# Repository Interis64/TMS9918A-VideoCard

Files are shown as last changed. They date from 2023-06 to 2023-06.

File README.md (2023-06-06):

# TMS9918A-VideoCard

Interis 64 Video Card with TMS9918A chip

## Notes

The TMS9918A only requires 4116 DRAM, but to simplify voltage requirements, 4164 DRAM is used instead, as 4164 DRAM only requires a single 5V supply, while 4116 requires a 12V and -5V supply as well. The extra memory space is unused.

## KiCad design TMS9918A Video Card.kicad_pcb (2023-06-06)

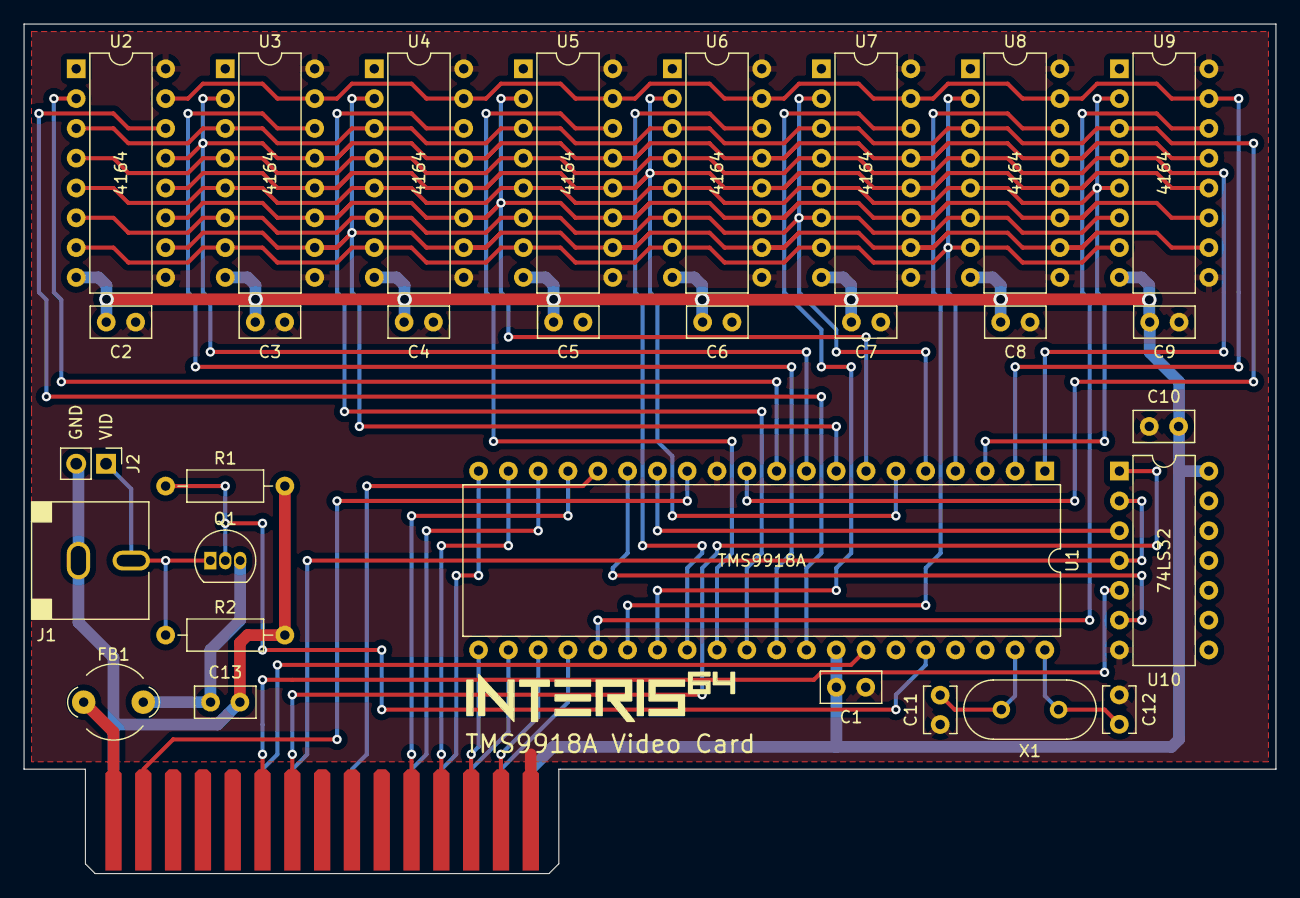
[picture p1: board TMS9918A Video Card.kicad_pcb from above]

Board: 2 copper layers, 106.7 x 72.4 mm, 31 parts (0 on the bottom side), 44 nets.

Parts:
C1, C2, C3, C4, C5, C6, C7, C8, C9, C10, C13: 0.1µF; C_Disc_D5.0mm_W2.5mm_P2.50mm
C11, C12: 27pF; C_Disc_D3.8mm_W2.6mm_P2.50mm
FB1: FerriteBead_Small; LairdTech_28C0236-0JW-10
J1: Video Out; Jack_RCA_CUI_RCJ-04
J2: Video Out; PinHeader_1x02_P2.54mm_Vertical
J4: Edge Connector; Interis_Expansion_PCBEdge
Q1: 2N4401; TO-92_Inline
R1: 470; R_Axial_DIN0207_L6.3mm_D2.5mm_P10.16mm_Horizontal
R2: 75; R_Axial_DIN0207_L6.3mm_D2.5mm_P10.16mm_Horizontal
U1: TMS9918A; DIP-40_W15.24mm
U2, U3, U4, U5, U6, U7, U8, U9: 4164; DIP-16_W7.62mm
U10: 74LS32; DIP-14_W7.62mm
X1: 10.738635 MHz; Crystal_HC49-U_Vertical

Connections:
+5V: C1.1, C2.1, C3.1, C4.1, C5.1, C6.1, C7.1, C8.1, C9.1, C10.1, J4.b15 (+5V), U1.33 (Vcc), U2.8 (Vcc), U3.8 (Vcc), U4.8 (Vcc), U5.8 (Vcc), U6.8 (Vcc), U7.8 (Vcc), U8.8 (Vcc), U9.8 (Vcc), U10.14 (VCC)
+5VA: FB1.1, J4.a1 (+5V)
/COMVID: Q1.2 (B), R1.1, U1.36 (COMVID)
/FilteredPower: C13.1, FB1.2, Q1.3 (C)
A0: J4.a2 (A0), U1.13 (MODE)
AD0: U1.10 (AD0), U2.2 (DI)
AD1: U1.9 (AD1), U2.13 (A6), U3.2 (DI), U3.13 (A6), U4.13 (A6), U5.13 (A6), U6.13 (A6), U7.13 (A6), U8.13 (A6), U9.13 (A6)
AD2: U1.8 (AD2), U2.10 (A5), U3.10 (A5), U4.2 (DI), U4.10 (A5), U5.10 (A5), U6.10 (A5), U7.10 (A5), U8.10 (A5), U9.10 (A5)
AD3: U1.7 (AD3), U2.11 (A4), U3.11 (A4), U4.11 (A4), U5.2 (DI), U5.11 (A4), U6.11 (A4), U7.11 (A4), U8.11 (A4), U9.11 (A4)
AD4: U1.6 (AD4), U2.12 (A3), U3.12 (A3), U4.12 (A3), U5.12 (A3), U6.2 (DI), U6.12 (A3), U7.12 (A3), U8.12 (A3), U9.12 (A3)
AD5: U1.5 (AD5), U2.6 (A2), U3.6 (A2), U4.6 (A2), U5.6 (A2), U6.6 (A2), U7.2 (DI), U7.6 (A2), U8.6 (A2), U9.6 (A2)
AD6: U1.4 (AD6), U2.7 (A1), U3.7 (A1), U4.7 (A1), U5.7 (A1), U6.7 (A1), U7.7 (A1), U8.2 (DI), U8.7 (A1), U9.7 (A1)
AD7: U1.3 (AD7), U2.5 (A0), U3.5 (A0), U4.5 (A0), U5.5 (A0), U6.5 (A0), U7.5 (A0), U8.5 (A0), U9.2 (DI), U9.5 (A0)
D0: J4.a11 (D0), U1.17 (CD7)
D1: J4.b11 (D1), U1.18 (CD6)
D2: J4.a12 (D2), U1.19 (CD5)
D3: J4.b12 (D3), U1.20 (CD4)
D4: J4.a13 (D4), U1.21 (CD3)
D5: J4.b13 (D5), U1.22 (CD2)
D6: J4.a14 (D6), U1.23 (CD1)
D7: J4.b14 (D7), U1.24 (CD0)
GND: C1.2, C2.2, C3.2, C4.2, C5.2, C6.2, C7.2, C8.2, C9.2, C10.2, C11.2, C12.1, J4.a15 (GND), U1.12 (GND), U2.9 (A7), U2.16 (GND), U3.9 (A7), U3.16 (GND), U4.9 (A7), U4.16 (GND), U5.9 (A7), U5.16 (GND), U6.9 (A7), U6.16 (GND), U7.9 (A7), U7.16 (GND), U8.9 (A7), U8.16 (GND), U9.9 (A7), U9.16 (GND), U10.7 (GND)
GNDA: C13.2, J1.2 (Ext), J2.2, J4.b1 (GND), R1.2, R2.2
unnamed: C11.1, U1.39 (X1), X1.2
unnamed: C12.2, U1.40 (X2), X1.1
unnamed: J1.1 (In), J2.1, Q1.1 (E), R2.1
unnamed: U1.14 (~CSW), U10.3
unnamed: U1.15 (~CSR), U10.6
RD0: U1.32 (RD0), U2.14 (DO)
RD1: U1.31 (RD1), U3.14 (DO)
RD2: U1.30 (RD2), U4.14 (DO)
RD3: U1.29 (RD3), U5.14 (DO)
RD4: U1.28 (RD4), U6.14 (DO)
RD5: U1.27 (RD5), U7.14 (DO)
RD6: U1.26 (RD6), U8.14 (DO)
RD7: U1.25 (RD7), U9.14 (DO)
R/~W: U1.11 (R/~W), U2.3 (~WE), U3.3 (~WE), U4.3 (~WE), U5.3 (~WE), U6.3 (~WE), U7.3 (~WE), U8.3 (~WE), U9.3 (~WE)
~CAS: U1.2 (~CAS), U2.15 (~CAS), U3.15 (~CAS), U4.15 (~CAS), U5.15 (~CAS), U6.15 (~CAS), U7.15 (~CAS), U8.15 (~CAS), U9.15 (~CAS)
~IRQ: J4.b9 (~IRQ), U1.16 (~INT)
~RAS: U1.1 (~RAS), U2.4 (~RAS), U3.4 (~RAS), U4.4 (~RAS), U5.4 (~RAS), U6.4 (~RAS), U7.4 (~RAS), U8.4 (~RAS), U9.4 (~RAS)
~RD: J4.a6 (~RD), U10.5
~RESET: J4.b6 (~RESET), U1.34 (~RESET/SYNC)
~SLOT: J4.b7 (~SLOT), U10.2, U10.4
~WR: J4.a7 (~WR), U10.1
